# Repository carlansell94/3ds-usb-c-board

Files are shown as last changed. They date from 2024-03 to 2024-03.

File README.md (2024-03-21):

A small board designed to replace the proprietary Nintendo 3DS dock charging port with a USB type C port. This board is suitable for official Nintendo 3DS, New 3DS, 3DS XL and New 3DS XL docks, which all contain the same small PCB on the inside.

Features:
* Includes pads for 5.1k&#937; resistors, to allow the use of 'smart' chargers.
* Board is a near drop-in replacement for the original.
* Pads on the + output allow the addition of a switch - bridge these pads with solder if you're not using one. Alternatively, use the switchless version of the board.

Minor alterations to the dock are required, due to the USB type C port being physically larger than the original. More details on the required sanding can be found [on my blog](https://qubitsandbytes.co.uk/convert-a-nintendo-3ds-dock-to-usb-c/).

Included in this repository are the KiCAD files for this design. If you're only interested in having the board manufactured, gerbers are available under 'releases'.

Parts List:
* 1x 16 pin USB type C port
* 2x 0603 5.1k&#937; resistors (optional)
* 1x 2 pin switch (optional)

A tri-wing screwdriver is required, to remove the dock base.

When having the board manufactured, ensure they offer a 0.8mm board thickness - I used OSH Park for mine.

## Images
KiCAD render:

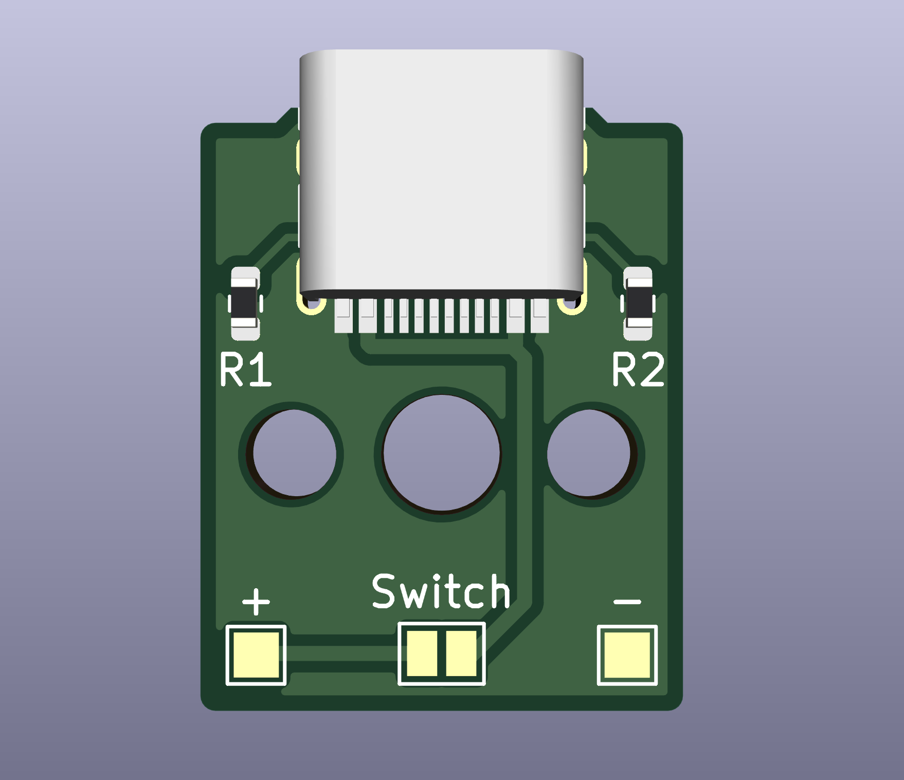
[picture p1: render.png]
KiCAD render KiCAD render of the board


## KiCAD
The files in this project were created using KiCAD 7. Older versions of KiCAD will be unable to open these files.

In addition, the USB Type C port pictured in the 3D render can be found [over here](https://github.com/ai03-2725/Type-C.pretty) - the file you're looking for is 'HRO TYPE-C-31-M-12.step'. It's not required, unless you want to see the part populated using the 3D viewer.

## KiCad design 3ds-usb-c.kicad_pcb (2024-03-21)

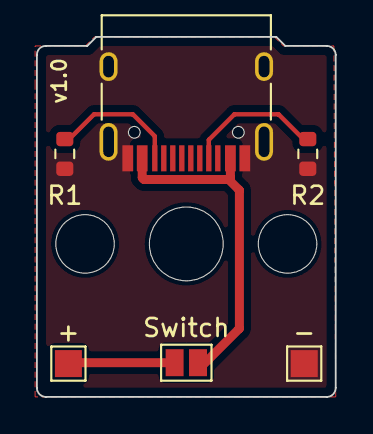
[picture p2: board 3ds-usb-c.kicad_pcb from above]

Board: 2 copper layers, 16.6 x 20.0 mm, 6 parts (0 on the bottom side), 5 nets.

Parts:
+: +; TestPoint_Pad_1.5x1.5mm
-: -; TestPoint_Pad_1.5x1.5mm
J1: USB_C_Receptacle; USB_C_Receptacle_HRO_TYPE-C-31-M-12
R1, R2: 5.1k; R_0603_1608Metric
Switch: SolderJumper-2_P1.3mm_Open_Pad1.0x1.5mm

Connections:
GND: -.1, J1.A1 (GND), J1.A12 (GND), J1.B1 (GND), J1.B12 (GND), J1.S1 (SHIELD), R1.2, R2.2
unnamed: J1.A4 (VBUS), J1.A9 (VBUS), J1.B4 (VBUS), J1.B9 (VBUS), Switch.1
unnamed: J1.A5 (CC1), R2.1
unnamed: J1.B5 (CC2), R1.1
unnamed: +.1, Switch.2

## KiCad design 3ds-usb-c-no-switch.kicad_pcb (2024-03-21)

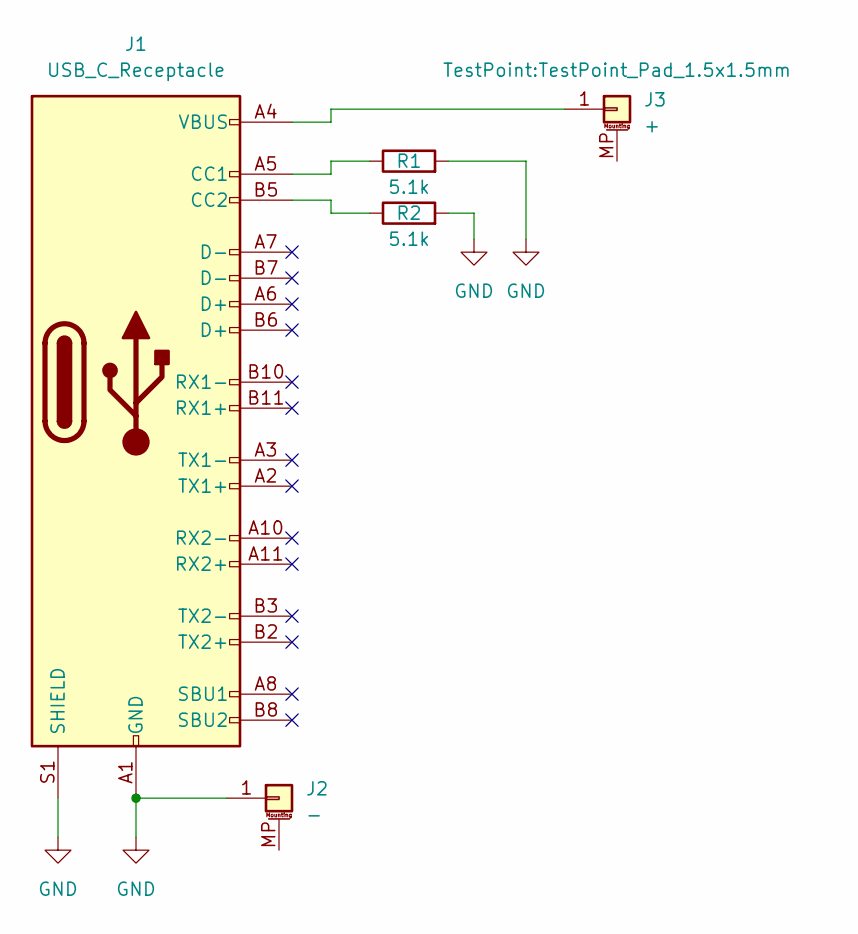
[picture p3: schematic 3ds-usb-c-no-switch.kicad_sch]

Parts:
J1: USB_C_Receptacle; USB_C_Receptacle_HRO_TYPE-C-31-M-12
J2: -; TestPoint_Pad_1.5x1.5mm
J3: +; TestPoint_Pad_1.5x1.5mm
R1, R2: 5.1k; R_0603_1608Metric

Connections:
GND: J1.A1 (GND), J1.A12 (GND), J1.B1 (GND), J1.B12 (GND), J1.S1 (SHIELD), J2.1, R1.2, R2.2
unnamed: J1.A5 (CC1), R1.1
unnamed: J1.B5 (CC2), R2.1
unnamed: J1.A4 (VBUS), J1.A9 (VBUS), J1.B4 (VBUS), J1.B9 (VBUS), J3.1

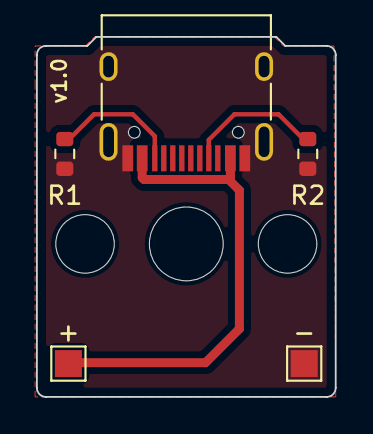
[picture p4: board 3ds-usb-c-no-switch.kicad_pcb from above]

Board: 2 copper layers, 16.6 x 20.0 mm, 5 parts (0 on the bottom side), 4 nets.
